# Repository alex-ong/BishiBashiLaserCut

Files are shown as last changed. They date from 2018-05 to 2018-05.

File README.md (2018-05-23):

## BishiBashiLaserCut
Laser cut plans for bishi bashi.
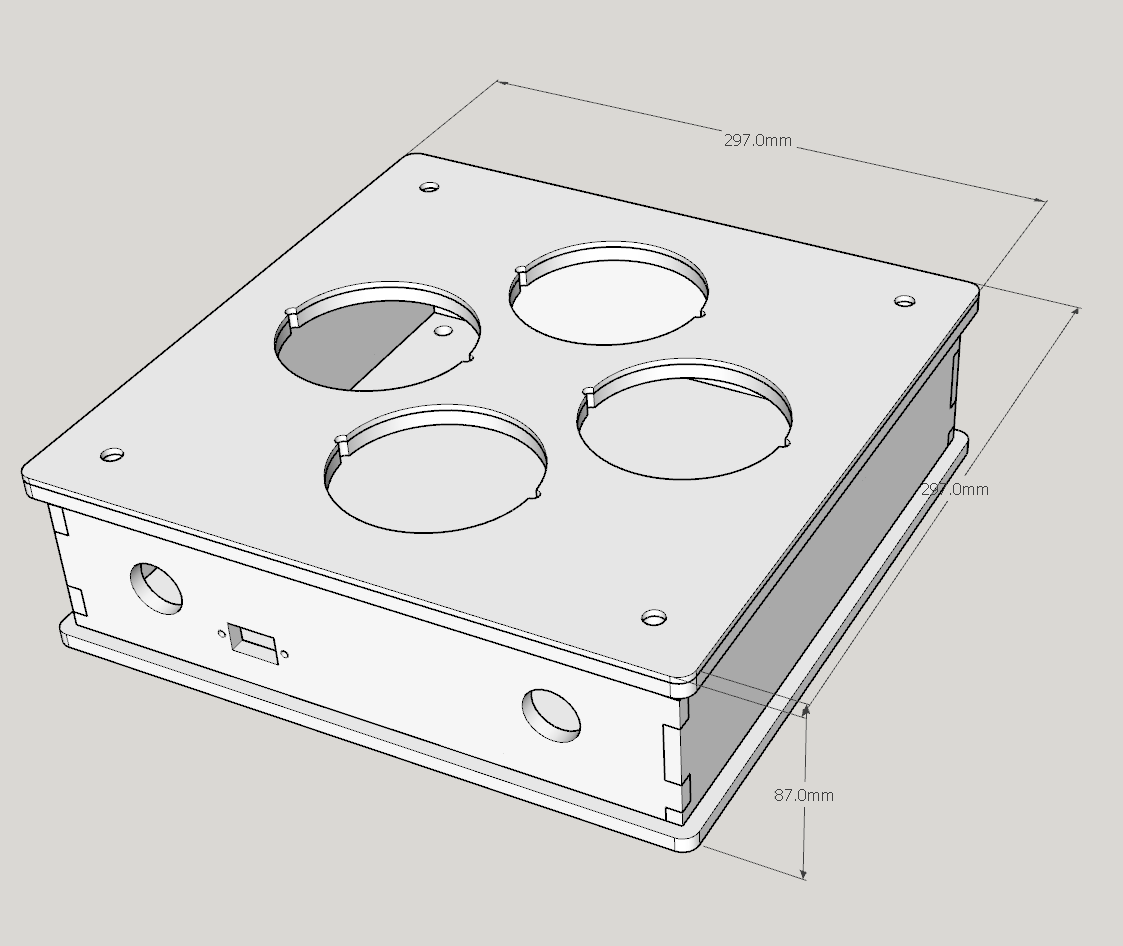
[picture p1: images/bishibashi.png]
BishiBashi Panel


## Build Materials

| Part | Qty | Type | Cost | 
| --- |:---:| --- | ---:|
| 400x600 x 7mm Plywood | 2 | Laser Cut (tops, bottom, side) | $12 | 
| 420x297mm x 3mm Acrylic/Plywood | 1 | Laser Cut (top aesthetic panel) | $10 |

Total Cost (Panels): ~$22 AUD

## Laser Plans
| Part | Qty |  Link |
| --- |:---:| -----: |
| 297x297x7mm Top structural | 1 | [Link](../master/Lasercut/top-structural.svg) |
| 297x297x7mm Bottom structural | 1 | [Link](../master/Lasercut/bottom.svg) |
| 297x70x7mm Sides | 3 | [Link](../master/Lasercut/side.svg) |
| 297x70x7mm Side(ports) | 1 | [Link](../master/Lasercut/side-ports.svg) | 
| 297x297x3mm Top Aesthetic | 1 | [Link](../master/Lasercut/top-aesthetic.svg)  |

All files are designed to print on < A3 size acrylic/timber other cuttable material, this size is often found at a good price on ebay or cut to order places. 

## Purchase Parts

| Part | Qty | Cost | Image | Source |
| --- |:---:| ---: | ----- | ---|
| 100mm Dome LED Lit PushButton (various colors) | 4 | 2 for $15.11 AUD |  [Red](../master/images/red.jpg) [Green](../master/images/green.jpg) [blue](../master/images/blue.jpg) [yellow](../master/images/yellow.jpg) [schematic](../master/images/buttonplan.jpg) | ali express |
| 24mm arcade pushbutton (start/coin) | 2 | $1.60 AUD each|  [Link](../master/images/startButton.jpg) | ebay |
| Zero Delay USB Encoder PC  (with quick disconnect)| 1 | $6.86 AUD |  [Link](../master/images/usbencoder.jpg) | ebay |
| M8 X 40MM NYLON PAN HEAD PHILLIPS SCREWS PLASTIC  | 8 | $3.09 AUD |  [Link](../master/images/panhead.jpg) | ebay |
| M8 X 20MM White plastic nylon non-threaded spacer | 4 | $2.90 AUD |  [Link](../master/images/spacer.jpg) | ebay |
| M8 x 28MM Nut | 4 | $5.47 AUD |  [Link](../master/images/hexnut.jpg) | ebay |
| 10mm high Rubber feet (adhesive or screw on) | 4 | $5.84 AUD |  [Link](../master/images/feet.jpg) | ebay |

Total cost (parts): $57.58 AUD

## Optional quick disconnect cable parts
| Part | Qty | Cost | Image | Source |
| --- |:---:| ---: | ----- | ---|
| USB-A to USB-B Panel mount | 1 | $2.74 AUD |  [Link](../master/images/panelmount.jpg) | ebay |
| USB-B to USB A cable | 1 | $1.57 AUD |  [Link](../master/images/printercable.jpg) | ebay |
| M3 x 20mm Screws (for mounting USB-B) | 2 | $6.00 for a kit with nuts etc|  [Link](../master/images/m3kit.jpg) | ebay |
| M3 nut  (for mounting USB-B) | 2 | Comes with screws | | ebay |

Total cost (optional): $10.31 AUD

## Assembly
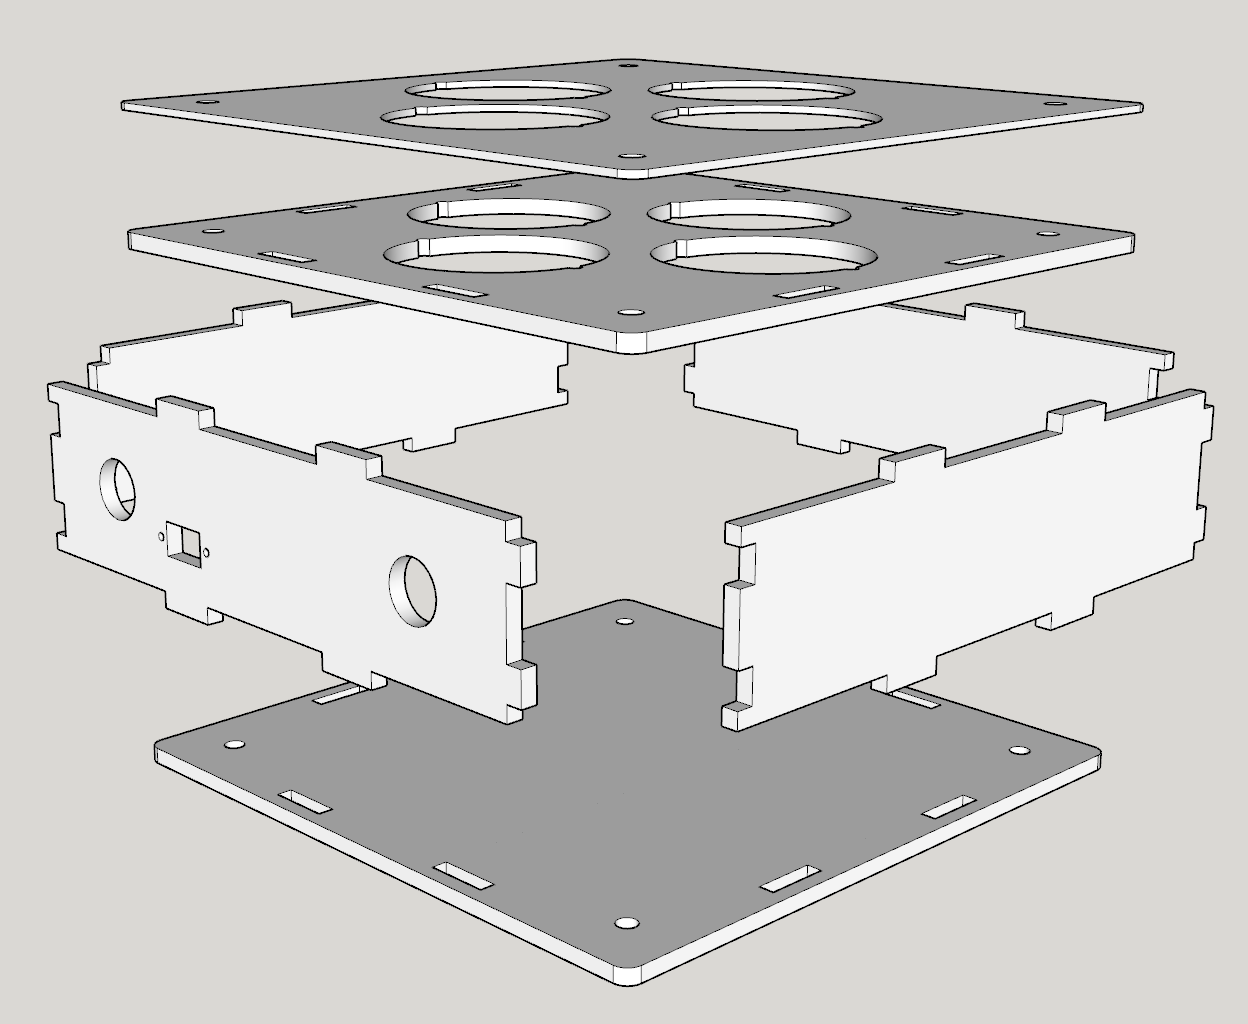
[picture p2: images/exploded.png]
BishiBashi Exploded

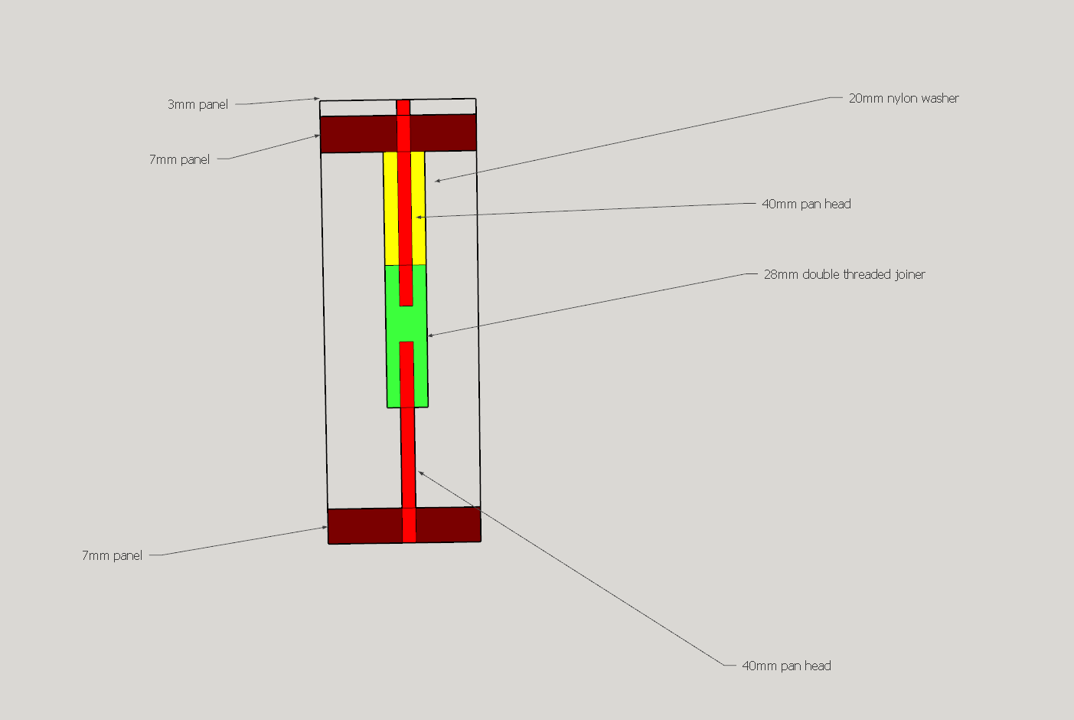
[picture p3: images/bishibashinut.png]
BishiBashi Nut


1. Laser cut everything, buy all parts etc.
2. Stack Aesthetic and structural top plate.
3. Place 100mm Dome Buttons through cutouts, and screw from beneath
4. Attach 24mm buttons to side ports
5. Glue zero delay USB encoder to bottom of top panel. Attach all buttons and test with computer.
6. Attach usb encoder to USB-A to USB-B and then to USB-B back to USB-A. Test with computer
7. Panel mount the USB-A to USB-B using M3x20mm and M3 nuts
8. Screw in 4 of the M8 x 40mm screws, using a white spacer and the nut, via top panel.
9. Attach any rubber feet to bottom now.
10. Assemble rest of panels together.
11. Screw in final 4 screws.

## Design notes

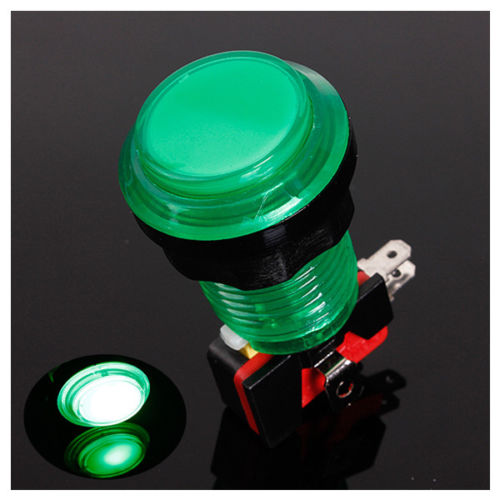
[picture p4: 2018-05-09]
images/startButton.jpg

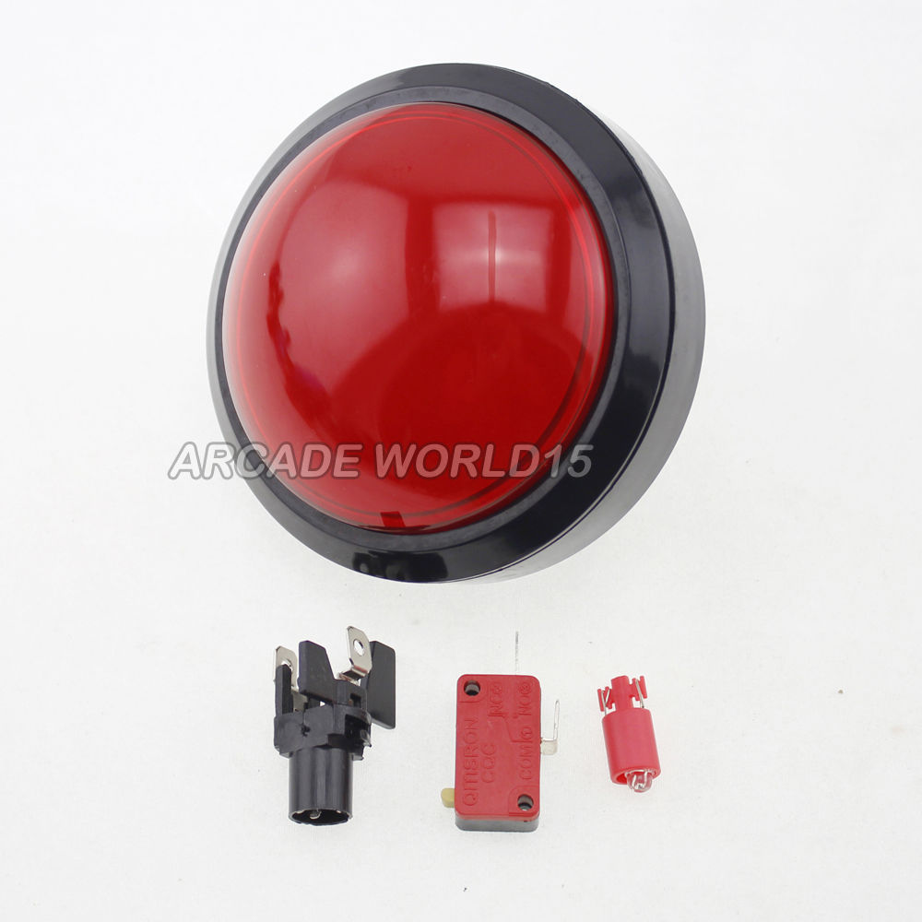
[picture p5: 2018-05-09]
images/red.jpg

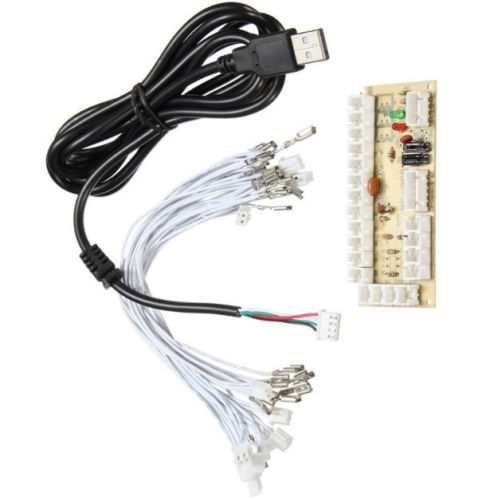
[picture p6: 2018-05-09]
images/usbencoder.jpg

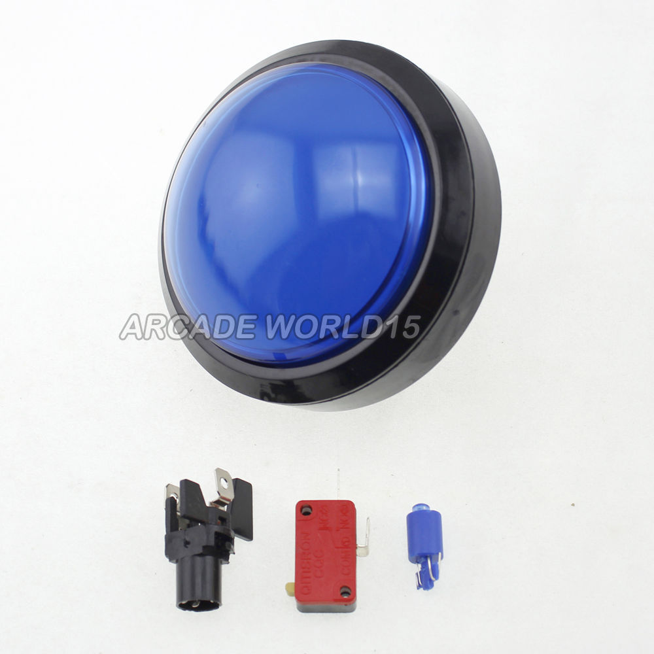
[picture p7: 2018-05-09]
images/blue.jpg

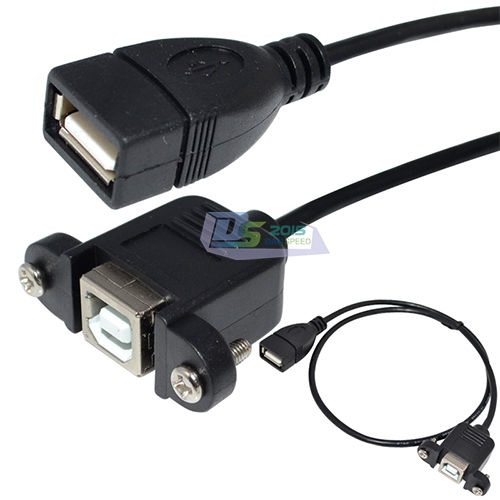
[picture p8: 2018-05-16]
images/panelmount.jpg

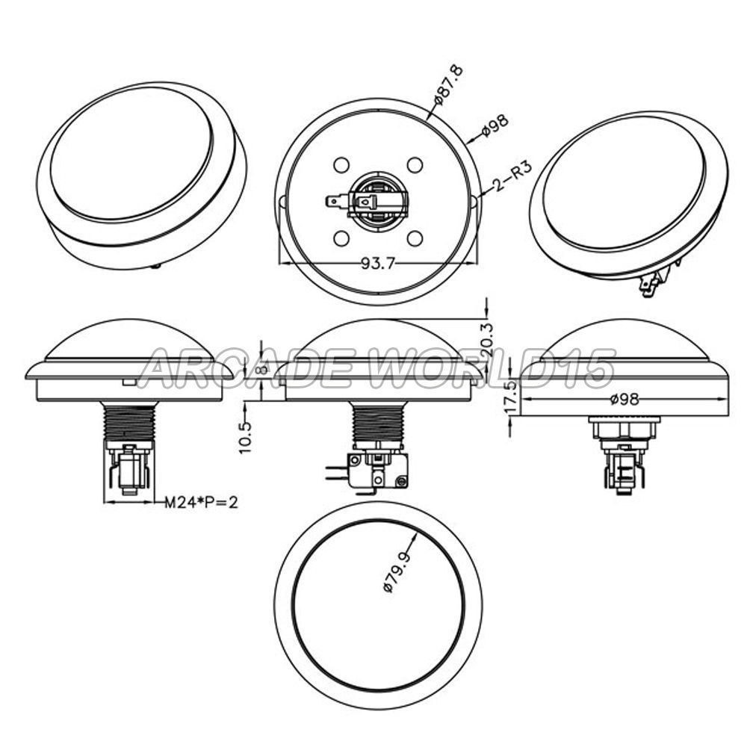
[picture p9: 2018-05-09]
images/buttonplan.jpg

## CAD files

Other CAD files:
Sketchup/cabinet.skp

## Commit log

2018-05-09 Added sketchup and svg files
    [cabinet.skp]
2018-05-23 Renamed bishibashi-nut since it wasn't showing up
